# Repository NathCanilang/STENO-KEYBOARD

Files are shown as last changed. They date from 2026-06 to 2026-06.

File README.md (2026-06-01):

# Steno-Keyboard Firmware

High-performance firmware for RP2040/RP2350 based stenography keyboards, built using the Raspberry Pi Pico SDK and TinyUSB.

## Features

- **Matrix Scanning**: Efficient 11x6 matrix scanning implementation.
- **HID Protocol**: Custom 4-byte (27-key) HID bitmap reports for NKRO (N-Key Rollover) support.
- **Debouncing**: Eager debouncing logic for minimal latency.
- **USB Stack**: Integrated TinyUSB for lightweight HID communication.

## Project Structure

- [Steno-Keyboard.c](Steno-Keyboard.c): Main entry point and hardware initialization.
- [keyboard.c](keyboard.c): Matrix scanning and HID report generation logic.
- [usb_descriptors.c](usb_descriptors.c): USB descriptor definitions.
- [sys_debounce/](sys_debounce/): Core debouncing implementation.

## Getting Started

### Prerequisites

- [Raspberry Pi Pico SDK](https://github.com/raspberrypi/pico-sdk)
- CMake (3.13+)
- Ninja or Make build system

### Build Instructions

1. Create and enter the build directory:
   ```bash
   mkdir build
   cd build
   ```

2. Generate build files:
   ```bash
   cmake ..
   ```

3. Compile the project:
   ```bash
   ninja
   ```

4. Flash the `Steno-Keyboard.uf2` file to the device.

## Technical Notes

- **HID Buffer Size**: The HID report buffer is configured to 32 bytes to accommodate the custom bitmap structure.
- **Chord Collection**: Implements a buffer collection mechanism to ensure synchronized delivery of stenographic chords.
- **SDK Usage**: Utilizes native Pico SDK hardware APIs for optimal performance.

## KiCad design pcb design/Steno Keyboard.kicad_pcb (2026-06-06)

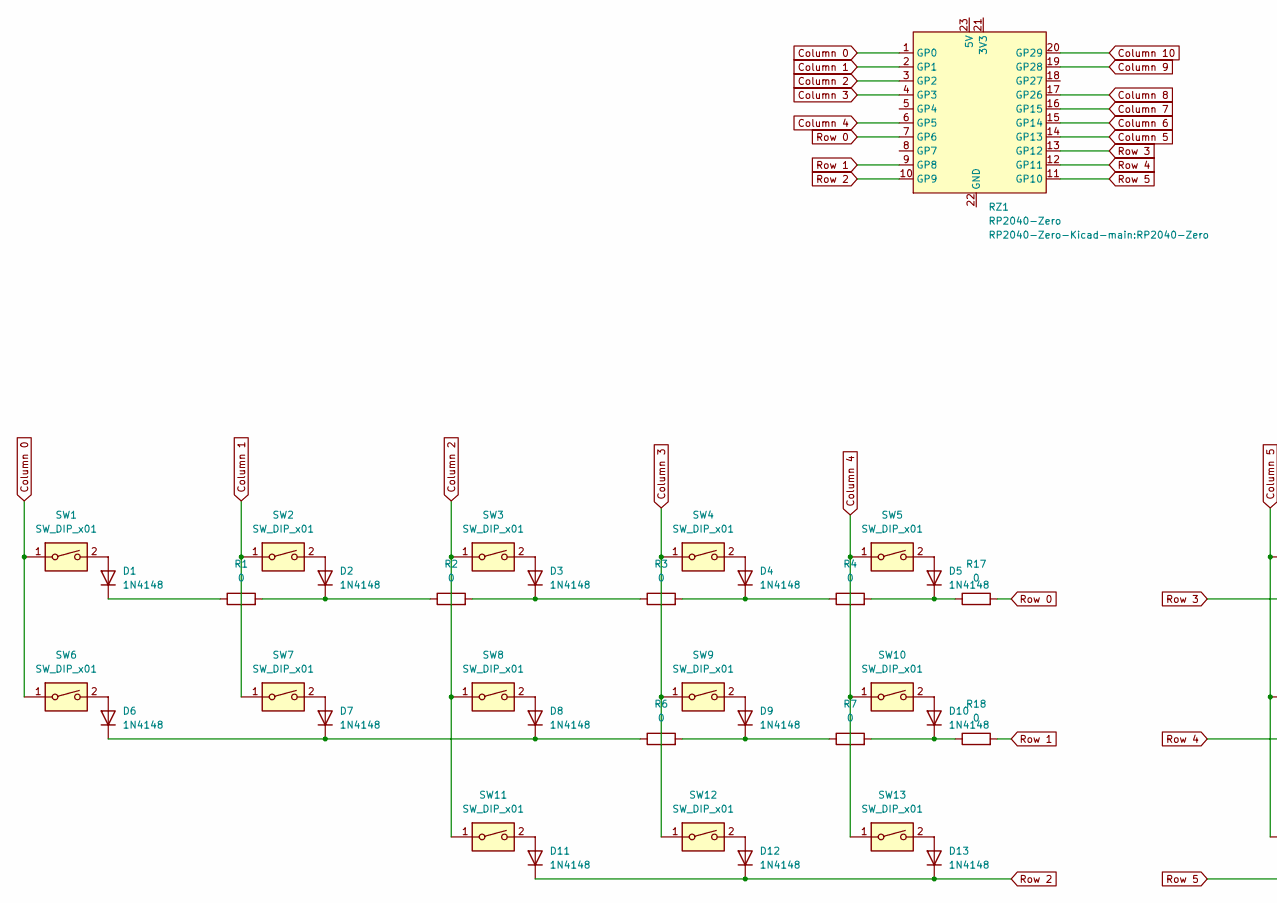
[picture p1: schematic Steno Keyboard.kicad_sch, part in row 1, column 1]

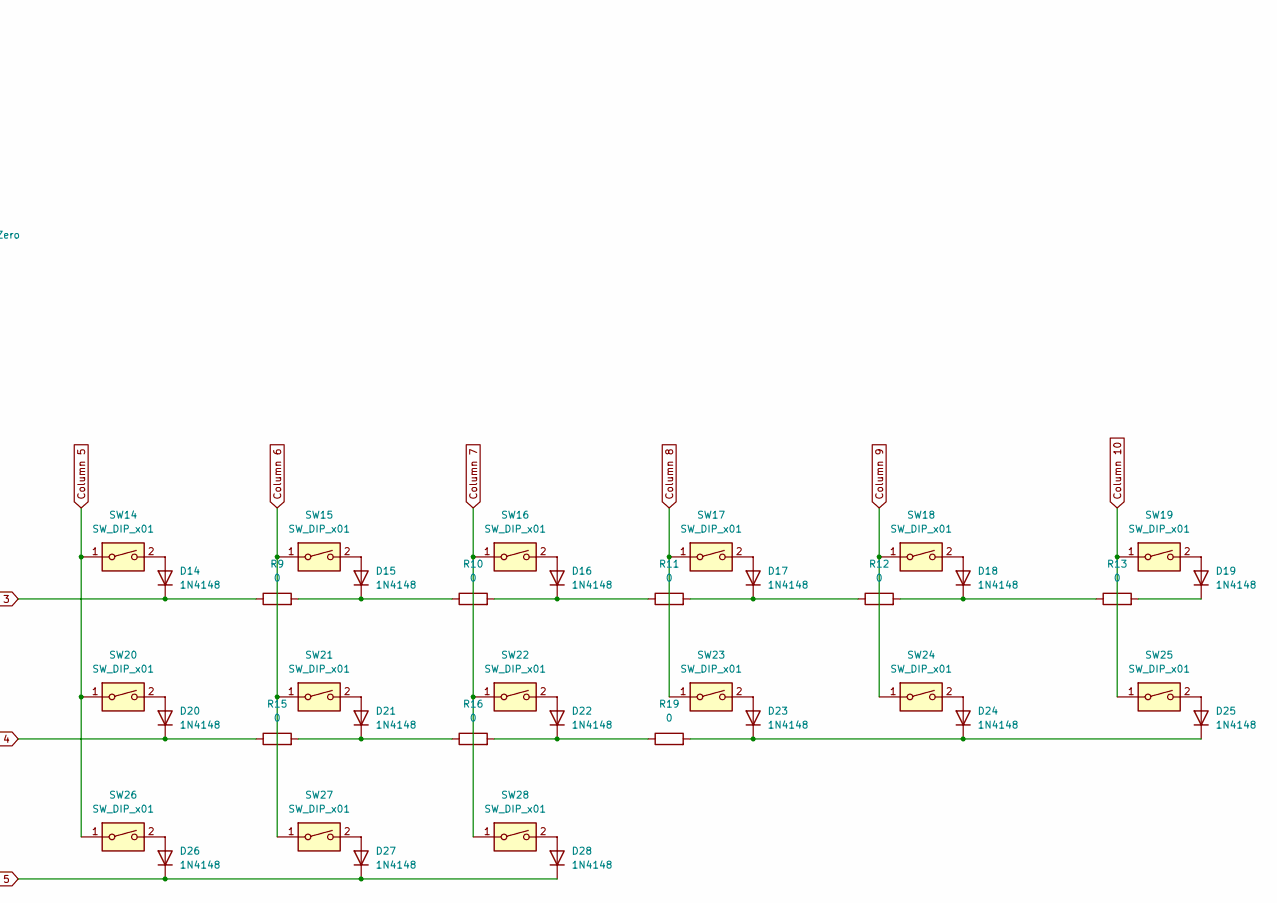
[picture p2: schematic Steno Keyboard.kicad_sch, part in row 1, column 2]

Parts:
D1, D2, D3, D4, D5, D6, D7, D8, D9, D10, D11, D12, D13, D14, D15, D16, D17, D18, D19, D20, D21, D22, D23, D24, D25, D26, D27, D28: 1N4148; D_SOD-123
R1, R2, R3, R4, R6, R7, R9, R10, R11, R12, R13, R15, R16, R17, R18, R19: 0; R_1206_3216Metric_Pad1.30x1.75mm_HandSolder
RZ1: RP2040-Zero
SW1, SW2, SW3, SW4, SW5, SW6, SW7, SW8, SW9, SW10, SW11, SW12, SW13, SW14, SW15, SW16, SW17, SW18, SW19, SW20, SW21, SW22, SW23, SW24, SW25, SW26, SW27, SW28: SW_DIP_x01; Kailh_socket_MX

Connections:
Column 0: RZ1.1 (GP0), SW1.1, SW6.1
Column 1: RZ1.2 (GP1), SW2.1, SW7.1
Column 2: RZ1.3 (GP2), SW3.1, SW8.1, SW11.1
Column 3: RZ1.4 (GP3), SW4.1, SW9.1, SW12.1
Column 4: RZ1.6 (GP5), SW5.1, SW10.1, SW13.1
Column 5: RZ1.14 (GP13), SW14.1, SW20.1, SW26.1
Column 6: RZ1.15 (GP14), SW15.1, SW21.1, SW27.1
Column 7: RZ1.16 (GP15), SW16.1, SW22.1, SW28.1
Column 8: RZ1.17 (GP26), SW17.1, SW23.1
Column 9: RZ1.19 (GP28), SW18.1, SW24.1
Column 10: RZ1.20 (GP29), SW19.1, SW25.1
unnamed: D1.2 (A), SW1.2
unnamed: D1.1 (K), R1.1
unnamed: D2.2 (A), SW2.2
unnamed: D2.1 (K), R1.2, R2.1
unnamed: D3.2 (A), SW3.2
unnamed: D3.1 (K), R2.2, R3.1
unnamed: D4.2 (A), SW4.2
unnamed: D4.1 (K), R3.2, R4.1
unnamed: D5.2 (A), SW5.2
unnamed: D5.1 (K), R4.2, R17.1
unnamed: D6.2 (A), SW6.2
unnamed: D6.1 (K), D7.1 (K), D8.1 (K), R6.1
unnamed: D7.2 (A), SW7.2
unnamed: D8.2 (A), SW8.2
unnamed: D9.2 (A), SW9.2
unnamed: D9.1 (K), R6.2, R7.1
unnamed: D10.2 (A), SW10.2
unnamed: D10.1 (K), R7.2, R18.1
unnamed: D11.2 (A), SW11.2
unnamed: D12.2 (A), SW12.2
unnamed: D13.2 (A), SW13.2
unnamed: D14.2 (A), SW14.2
unnamed: D15.2 (A), SW15.2
unnamed: D15.1 (K), R9.2, R10.1
unnamed: D16.2 (A), SW16.2
unnamed: D16.1 (K), R10.2, R11.1
unnamed: D17.2 (A), SW17.2
unnamed: D17.1 (K), R11.2, R12.1
unnamed: D18.2 (A), SW18.2
unnamed: D18.1 (K), R12.2, R13.1
unnamed: D19.2 (A), SW19.2
unnamed: D19.1 (K), R13.2
unnamed: D20.2 (A), SW20.2
unnamed: D21.2 (A), SW21.2
unnamed: D21.1 (K), R15.2, R16.1
unnamed: D22.2 (A), SW22.2
unnamed: D22.1 (K), R16.2, R19.1
unnamed: D23.2 (A), SW23.2
unnamed: D23.1 (K), D24.1 (K), D25.1 (K), R19.2
unnamed: D24.2 (A), SW24.2
unnamed: D25.2 (A), SW25.2
unnamed: D26.2 (A), SW26.2
unnamed: D27.2 (A), SW27.2
unnamed: D28.2 (A), SW28.2
Row 0: R17.2, RZ1.7 (GP6)
Row 1: R18.2, RZ1.9 (GP8)
Row 2: D11.1 (K), D12.1 (K), D13.1 (K), RZ1.10 (GP9)
Row 3: D14.1 (K), R9.1, RZ1.13 (GP12)
Row 4: D20.1 (K), R15.1, RZ1.12 (GP11)
Row 5: D26.1 (K), D27.1 (K), D28.1 (K), RZ1.11 (GP10)

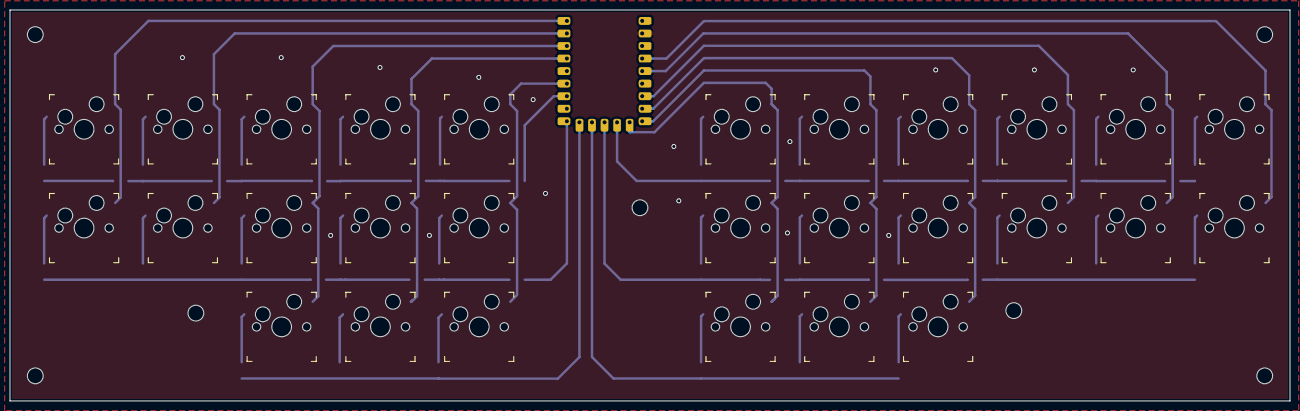
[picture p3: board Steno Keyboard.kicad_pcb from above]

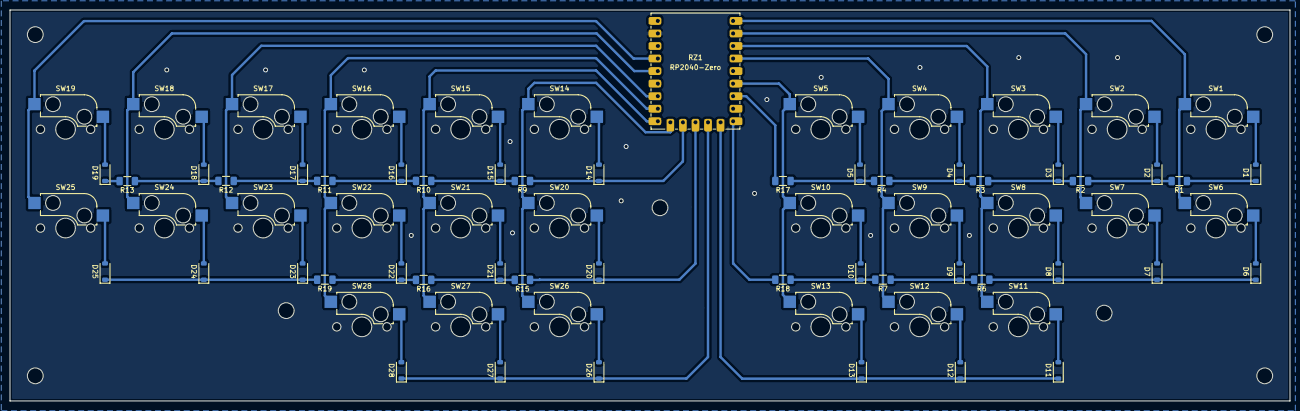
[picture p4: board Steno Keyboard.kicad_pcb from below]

Board: 2 copper layers, 259.2 x 79.2 mm, 73 parts (45 on the bottom side), 61 nets.

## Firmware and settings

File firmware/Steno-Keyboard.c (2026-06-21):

#include <stdlib.h>
#include <bsp/board_api.h>
#include <string.h>
#include <tusb.h>
#include <pico/stdio.h>
#include "keyboard.h"
#include <hardware/gpio.h>

void pin_init(void){
    // intialize all rows and col pins
    for(int i = 0; i < MATRIX_COLUMN; i++){
        gpio_init(col_pins[i]);
    }

    for(int i = 0; i < MATRIX_ROW; i++){
        gpio_init(row_pins[i]);
    }

    // //all column pin will be output
    for(int i = 0; i < MATRIX_COLUMN; i++){
        gpio_set_dir(col_pins[i], GPIO_OUT);
    }

    // all the row pins will be input
    for(int i = 0; i < MATRIX_ROW; i++){
        gpio_set_dir(row_pins[i], GPIO_IN);
    }


    // make them all 0 for now
    for(int i = 0; i < MATRIX_COLUMN; i++){
        gpio_put(col_pins[i], 0);
    }

    for(int i = 0; i < MATRIX_ROW; i++){
        gpio_pull_down(row_pins[i]);
    }
}

int main(void)
{
    // Initialize TinyUSB stack
    board_init();
    tusb_init();

    pin_init();
    while (true) {
        tud_task();
        keyboard_task();
    }
    return 0;
}

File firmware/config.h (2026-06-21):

// keyboard layout
#define LAYOUT(\
    k00, k01, k02, k03, k04,     k05, k06, k07, k08, k09, k10,\
    k11, k12, k13, k14, k15,     k16, k17, k18, k19, k20, k21,\
              k22, k23, k24,     k25, k26, k27\
) \
{ \
    /* ROW 0: Left Half (Cols 0-4). */ \
    { k00, k01, k02, k03, k04,     KC_NONE, KC_NONE, KC_NONE, KC_NONE, KC_NONE, KC_NONE }, \
    /* ROW 1: Left Half (Cols 0-4). */ \
    { k11, k12, k13, k14, k15,     KC_NONE, KC_NONE, KC_NONE, KC_NONE, KC_NONE, KC_NONE }, \
    /* ROW 2: Left Half (Cols 2-4).*/ \
    { KC_NONE, KC_NONE, k22, k23, k24,   KC_NONE, KC_NONE, KC_NONE, KC_NONE, KC_NONE, KC_NONE }, \
    \
    /* ROW 3: Right Half (Cols 5-10) */ \
    { KC_NONE, KC_NONE, KC_NONE, KC_NONE, KC_NONE,   k05, k06, k07, k08, k09, k10 }, \
    /* ROW 4: Right Half (Cols 5-10) */ \
    { KC_NONE, KC_NONE, KC_NONE, KC_NONE, KC_NONE,   k16, k17, k18, k19, k20, k21 }, \
    /* ROW 5: Right Half (Cols 5-7) */ \
    { KC_NONE, KC_NONE, KC_NONE, KC_NONE, KC_NONE,    k25, k26, k27, KC_NONE, KC_NONE, KC_NONE } \
}

// GPIO Declarations
#define COLUMN_00_PIN 0
#define COLUMN_01_PIN 1
#define COLUMN_02_PIN 2
#define COLUMN_03_PIN 3
#define COLUMN_04_PIN 5
#define COLUMN_05_PIN 13
#define COLUMN_06_PIN 14
#define COLUMN_07_PIN 15
#define COLUMN_08_PIN 26
#define COLUMN_09_PIN 28
#define COLUMN_10_PIN 29
#define ROW_00_PIN 6
#define ROW_01_PIN 8
#define ROW_02_PIN 9
#define ROW_03_PIN 12 
#define ROW_04_PIN 11
#define ROW_05_PIN 10

//bitmap configs
#define MATRIX_ROW 6
#define MATRIX_COLUMN 11
#define REQUIRED_BYTES 4

// TX Bolt Approach
#define KC_NONE       0xFF    // declare when key is empty 

// Byte 1
#define L_KC_H        0x05
#define L_KC_W        0x04
#define L_KC_P        0x03
#define L_KC_K        0x02
#define L_KC_T        0x01
#define L_KC_S        0x00

// Byte 2
#define R_KC_U        0x0D
#define R_KC_E        0x0C
#define KC_AST        0x0B
#define L_KC_O        0x0A
#define L_KC_A        0x09
#define L_KC_R        0x08

// Byte 3
#define R_KC_G        0x15
#define R_KC_L        0x14
#define R_KC_B        0x13
#define R_KC_P        0x12
#define R_KC_R        0x11
#define R_KC_F        0x10

// Byte 4
#define KC_HASH       0x1C 
#define R_KC_Z        0x1B
#define R_KC_D        0x1A
#define R_KC_S        0x19 
#define R_KC_T        0x18 

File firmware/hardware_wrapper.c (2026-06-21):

#include "hardware_wrapper.h"
#include <string.h>
#include <pico/stdio.h>
#include <hardware/gpio.h>
#include <pico/time.h>

#define PIN_COUNT 20

static bool mock_pins[PIN_COUNT] = { 0 }; //declare all pins as 0 output first
static uint32_t mock_time = 0;

void init_pins(uint8_t pin)
{
    gpio_init(pin);
}

void pin_set_dir(uint8_t pin, bool pin_dir)
{
    gpio_set_dir(pin, pin_dir);
}

bool get_pin_value(uint8_t pin)
{
    return gpio_get(pin);
}

void set_pin_output(uint8_t pin, bool output)
{
    gpio_put(pin, output);
}

uint32_t get_time_us(void)
{
    return to_ms_since_boot(get_absolute_time());
}

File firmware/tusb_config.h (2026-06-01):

#ifndef _TUSB_CONFIG_H_
#define _TUSB_CONFIG_H_

#ifdef __cplusplus
 extern "C" {
#endif

#define CFG_TUD_ENABLED         (1)

#ifndef CFG_TUSB_OS
#define CFG_TUSB_OS OPT_OS_NONE
#endif

// RHPort number used for device can be defined by board.mk, default to port 0
#ifndef BOARD_DEVICE_RHPORT_NUM
#define BOARD_DEVICE_RHPORT_NUM (0)
#endif

// Legacy RHPORT configuration
#define CFG_TUSB_RHPORT0_MODE (OPT_MODE_DEVICE | OPT_MODE_FULL_SPEED)
#ifndef BOARD_TUD_RHPORT
#define BOARD_TUD_RHPORT        (0)
#endif
// end legacy RHPORT

//------------------------
// DEVICE CONFIGURATION //
//------------------------

// Enable 2 CDC classes
#define CFG_TUD_CDC             (1)
#define CFG_TUD_HID             (1)
// Set CDC FIFO buffer sizes
#define CFG_TUD_CDC_RX_BUFSIZE  (64)
#define CFG_TUD_CDC_TX_BUFSIZE  (64)
#define CFG_TUD_CDC_EP_BUFSIZE  (64)
#define CFG_TUD_HID_EP_BUFSIZE  (64)

#ifndef CFG_TUD_ENDPOINT0_SIZE
#define CFG_TUD_ENDPOINT0_SIZE  (64)
#endif

#ifdef __cplusplus
 }
#endif

#endif /* _TUSB_CONFIG_H_ */

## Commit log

2026-06-01 created the basic firmware
    [Steno Keyboard.kicad_pcb, Steno Keyboard.kicad_sch]
2026-06-01 Fix: added the firmware
    [Steno-Keyboard.c, tusb_config.h]
2026-06-06 updated PCB design
    [Steno Keyboard.kicad_pcb, Steno Keyboard.kicad_sch]
2026-06-10 fixed the keyboard_task logic by rewriting it
    [hardware_wrapper.c]
